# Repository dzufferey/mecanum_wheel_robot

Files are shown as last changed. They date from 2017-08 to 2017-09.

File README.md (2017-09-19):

# Mecanum wheels robot

A small omnidirectional wheeled robot.

The robot is designed as part of a series of tutorials covering: CAD, prototyping, and programming.

The project is split among the following directories:
- [body](body)
- [code](code)
- [pcb](pcb)

Not everything is in this repository.
You will also need:
- a model for the [mecanum wheels](https://github.com/dzufferey/scadla/blob/master/src/main/scala/scadla/examples/MecanumWheel.scala), or [alternatives](https://www.thingiverse.com/search?q=mecanum) like [this](https://www.thingiverse.com/thing:1203230)
- a case for Raspberry Pi (look on [Thingiverse](http://www.thingiverse.com/))

The [HOWTO.md](HOWTO.md) file describe how to put things together.

## Attributions

- [Bosch Blue 10.8 volt battery container](https://www.thingiverse.com/thing:1246842) by topias5 is licensed under the CC-BY-NC license.
- references and model for [A4988 Stepper Motor Driver Carrier, Black Edition](https://www.pololu.com/product/2128), license unclear ...
- [KiCAD module for the stepper dirvers](https://github.com/jharvey/Cinch_enclosure_template/tree/master/KICAD_Project/PCB-modules/pololu) by Jared Harvey, license unclear ...
- [rpi3-bottom_netfabb.stl](https://www.thingiverse.com/thing:2413372) by sachingm is licensed under CC-BY.

## License

The content of this project itself is licensed under the [Creative Commons Attribution 3.0 license](http://creativecommons.org/licenses/by/3.0/us/deed.en_US), and the source code in the `code` folder is licensed under the [MIT license](http://opensource.org/licenses/mit-license.php).

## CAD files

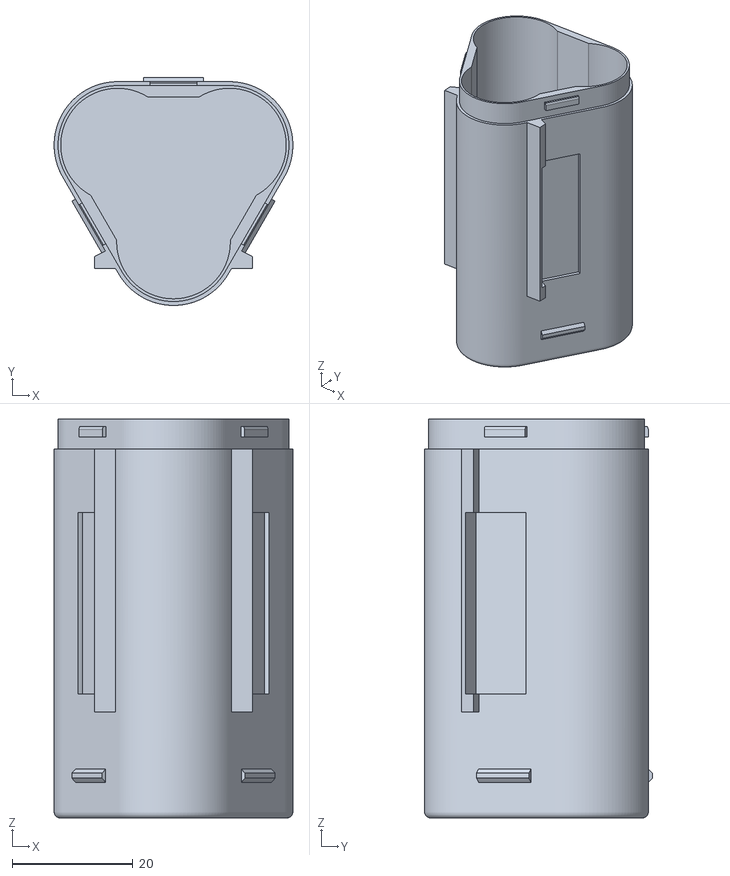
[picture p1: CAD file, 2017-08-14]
body/battery/Bosch_battery_108_body.stl
39.5 x 37.7 x 66.0

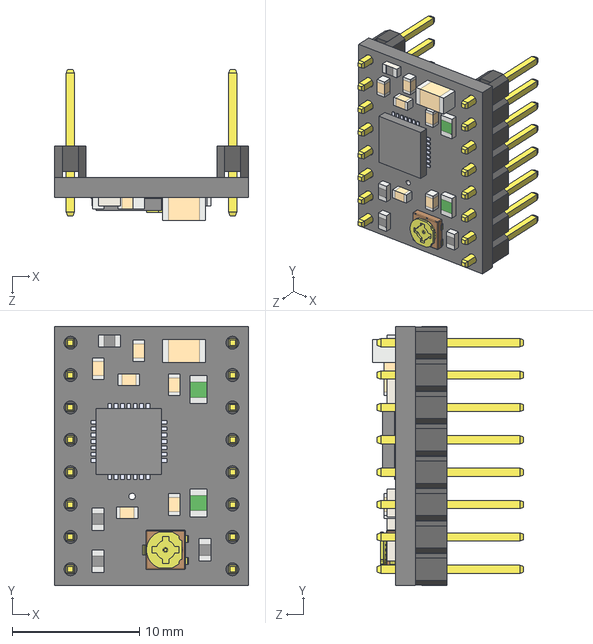
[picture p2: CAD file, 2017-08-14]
pcb/4_stepper_drivers/resources/a4988-stepper-motor-driver-carrier-black-edition.step
15.2 x 20.3 x 11.9 mm

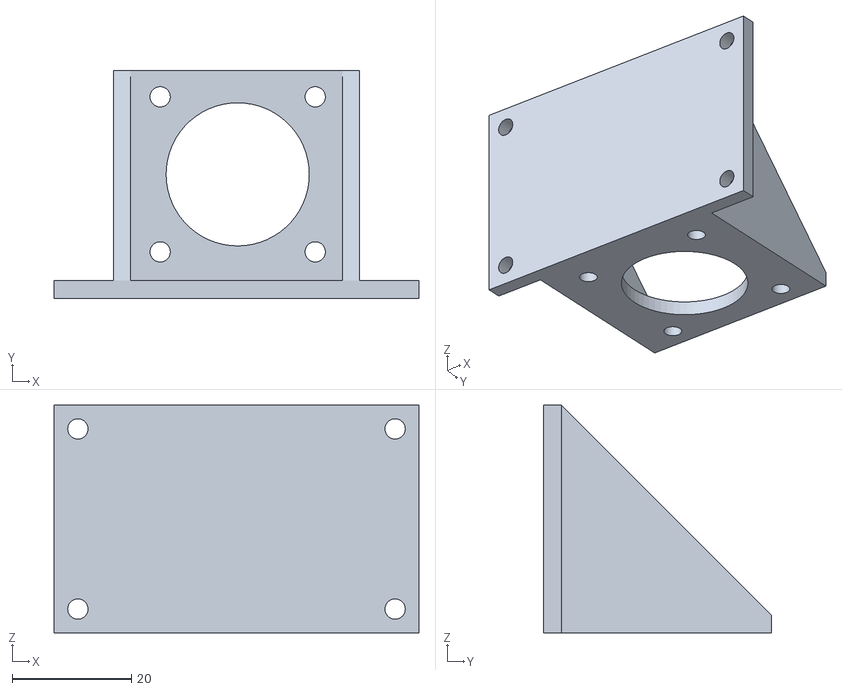
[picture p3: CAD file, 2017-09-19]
ready_to_make/body/nema14_bracket.stl
61.2 x 38.2 x 38.2

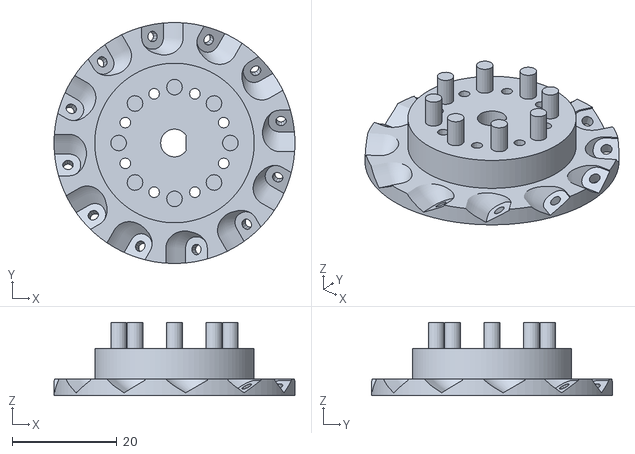
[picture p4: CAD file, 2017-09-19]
ready_to_make/body/wheel/lower1.stl
46.1 x 46.1 x 14.0

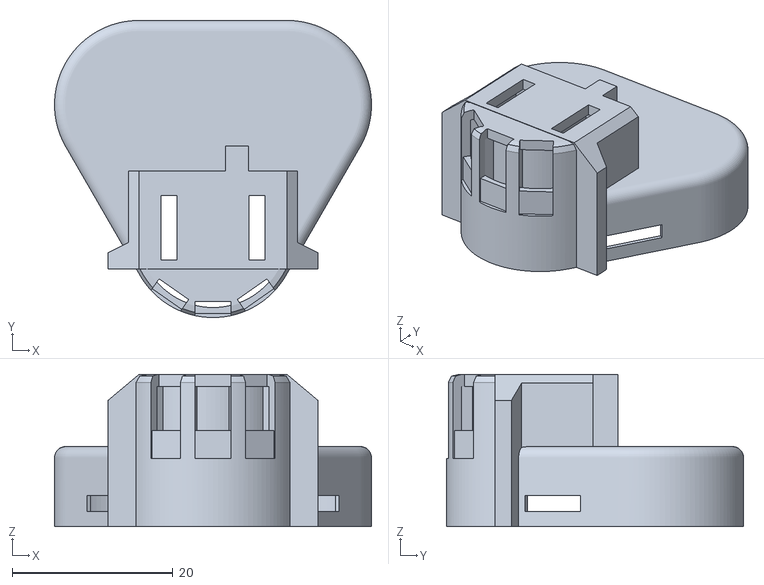
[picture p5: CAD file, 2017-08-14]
body/battery/Bosch_battery_108_top.stl
39.5 x 37.0 x 19.0

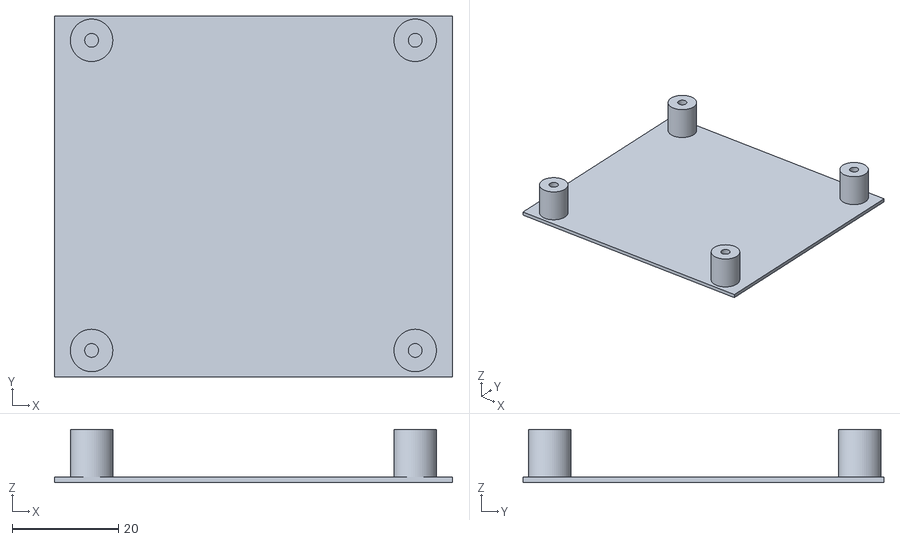
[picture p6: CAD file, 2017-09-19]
ready_to_make/body/pcb_base.stl
75.0 x 68.0 x 10.0

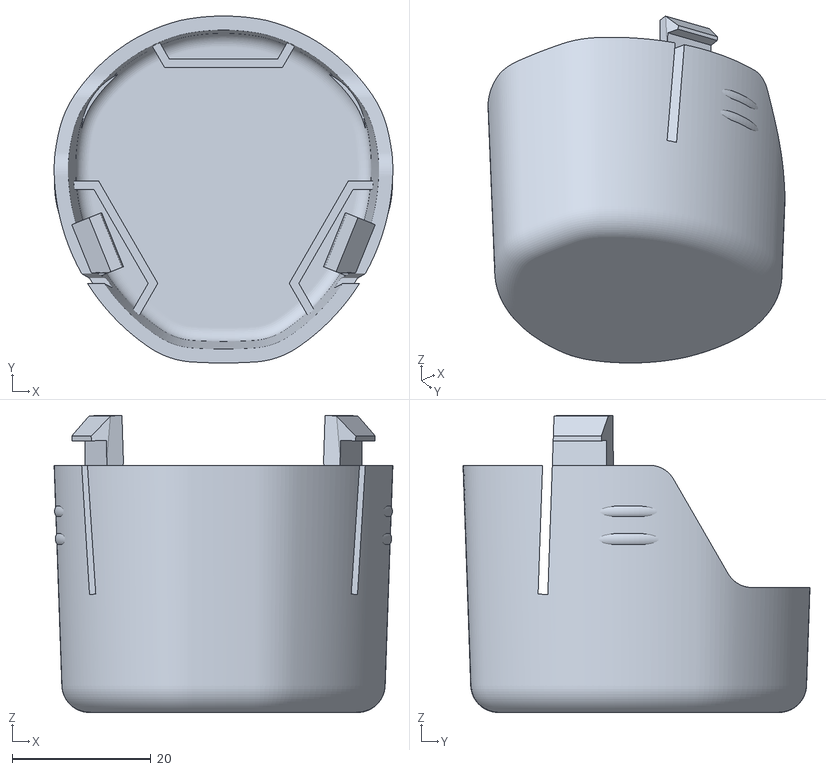
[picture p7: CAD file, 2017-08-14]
body/battery/Bosch_battery_108_cap.stl
48.8 x 50.0 x 42.8

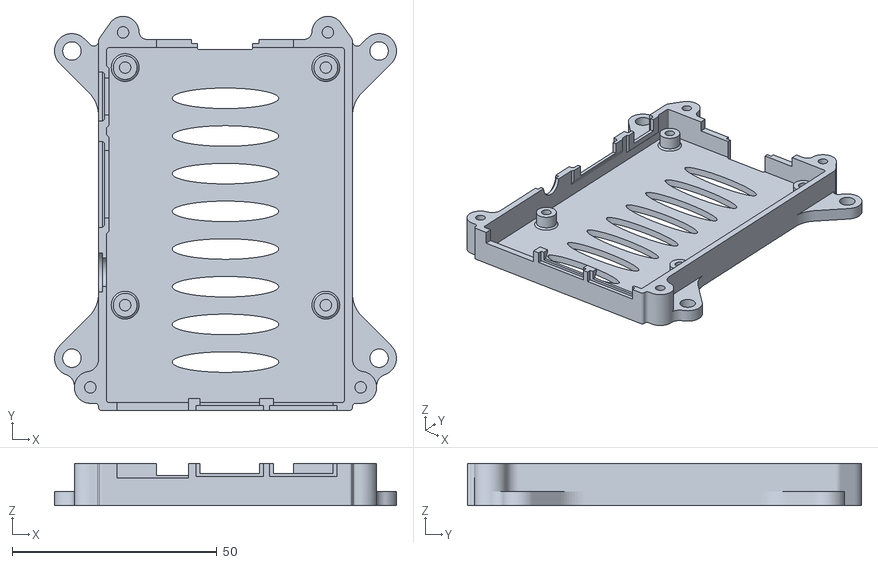
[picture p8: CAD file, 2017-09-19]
ready_to_make/body/rpi3-bottom_netfabb.stl
83.5 x 96.2 x 10.3

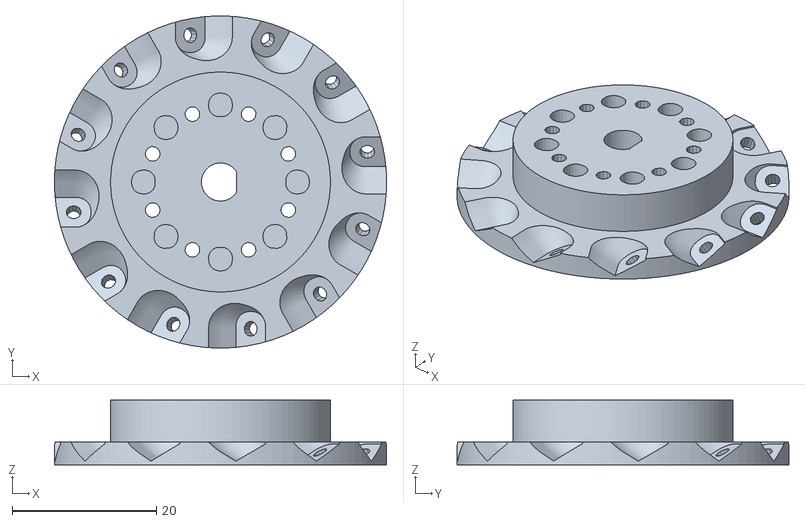
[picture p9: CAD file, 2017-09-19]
ready_to_make/body/wheel/upper1.stl
46.1 x 46.1 x 9.00

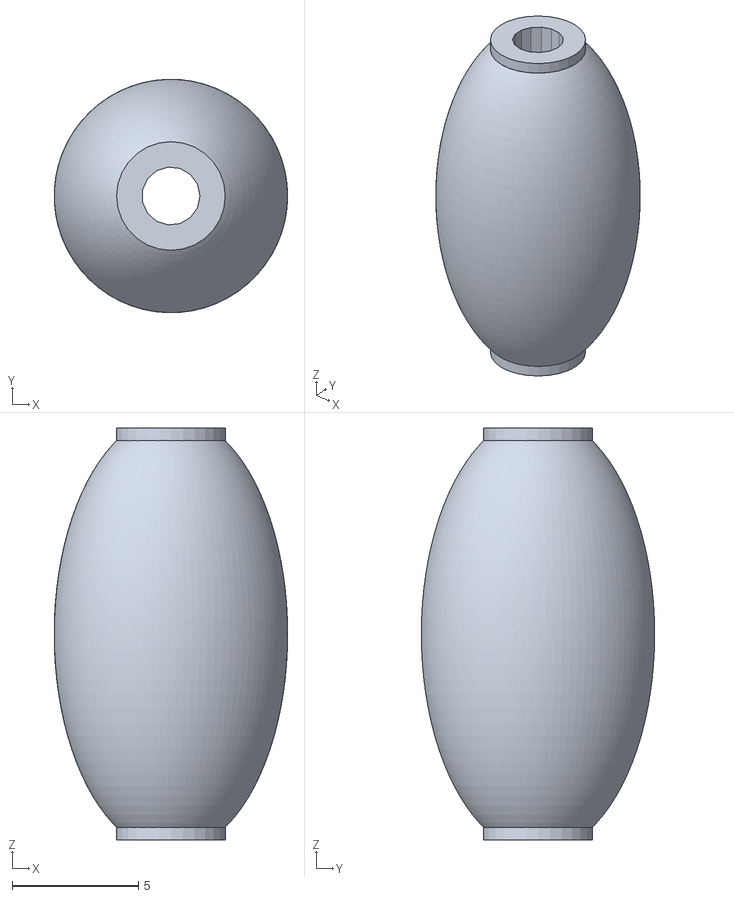
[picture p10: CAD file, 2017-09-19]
ready_to_make/body/wheel/roller.stl
9.23 x 9.24 x 16.3

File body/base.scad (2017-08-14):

$fn=60;

module pin(h = 10) {
    difference() {
        cylinder(r = 4, h = h);
        cylinder(r = 1.3, h = h);
    }
}

module base() {
    dx = 60.96;
    dy = 58.42;
    cube([75, 68, 1]);
    for (x = [0, dx])
        for (y = [0, dy])
            translate([7+x, 5 + y, 0]) pin();
}

base();

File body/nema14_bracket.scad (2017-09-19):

$fn=60;
wall=3;


tolerance = 0.2;
width = 35.2;
screw = 26;

r = (width - screw) / 2 + tolerance;
m3 = 1.5 + tolerance;

module shell() {
    difference() {
        hull(){
            difference() {
                translate([-wall,-wall,-wall]) cube([width+2*wall,width+wall,width+wall]);
                translate([-wall,0,0]) cube(width+2*wall);
            }
        }
        translate([-tolerance,-tolerance,-tolerance]) cube(width + 2*tolerance);
    }
    difference() {
        translate([-wall-10,-wall,-wall]) cube([width+2*wall+20,wall,width+wall]);
        for (x = [-6-wall, width + wall + 6]) {
            for (z = [4-wall,width-4]) {
                translate ([x,-wall, z]) rotate([-90,0,0]) translate ([0,0,-0.5]) cylinder(r=m3,h=wall+1);
             }
        }
    }
}

module complete() {
    difference() {
        translate([-r,-r, 0]) shell();
        translate([0,0,-wall]) {
            for (x = [0,screw]) {
                for (y = [0,screw]) {
                    translate ([x,y,0]) cylinder (r=m3,h=wall);
                }
            }
            translate ([screw/2,screw/2,0]) cylinder (r=12,h=wall);
        }
    }
}

complete();

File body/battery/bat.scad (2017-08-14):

$fn=60;

module top() {
    import("Bosch_battery_108_top.stl");
}

module mid() {
    import("Bosch_battery_108_body.stl");
}

module bot() {
    import("Bosch_battery_108_cap.stl");
}

module core(h) {
    rotate([0,0,30])cylinder(r=32, h=h,$fn=3);
}


module top_a() {
    intersection() {
        top();
        cylinder(r=25,h=10.0625);
    }
}

module top_b() {
    intersection() {
        top();
        translate([0,0,10.0625]) cylinder(r=25,h=15);
    }
}

module top2() {
    hull() intersection() {
        top_a();
        core(11);
    }
    top_a();
    hull() intersection() {
        top_b();
        core(30);
        translate([-10.5,-22.9,10]) cube([21,20,15]);
    }
    top_b();
}

module mid2(){
    hull() intersection() {
        mid();
        core(100);
    }
    mid();
}

module bot2(){
    hull() intersection() {
        bot();
        cylinder(r=30,h=18.0625);
    }
    hull() intersection() {
        bot();
        translate([0,0,18.0625]) cylinder(r=30,h=17.5);
    }
    hull() difference() {
        bot();
        translate([0,0,0]) cylinder(r=30,h=17.6 + 18.0625);
        translate([0,0,17.5 + 21.5]) cylinder(r=30,h=10);
    }
    hull() difference() {
        bot();
        translate([0,0,0]) cylinder(r=30,h=17.5 + 21.5);
    }
}

module bat() {
    translate([0,0,3]) {
        translate([0,0,61]) top2();
        mid2();
    }
    bot2();
}

module bigger_bat() {
    minkowski(){
        bat();
        sphere(r=0.5, $fn=30);
    }
}

module holder() {
    difference() {
        translate([0,2,0]) cylinder(r=25, h=47.5);
        translate([0,0,83]) rotate([180,0,0]) bigger_bat();
    }
}

module contacts() {
    translate([4.5,6,0]) cube([2,8,10]);
    translate([-6.5,6,0]) cube([2,8,10]);
}

holder();

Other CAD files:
ready_to_make/body/wheel/lower2.stl
ready_to_make/body/wheel/upper2.stl

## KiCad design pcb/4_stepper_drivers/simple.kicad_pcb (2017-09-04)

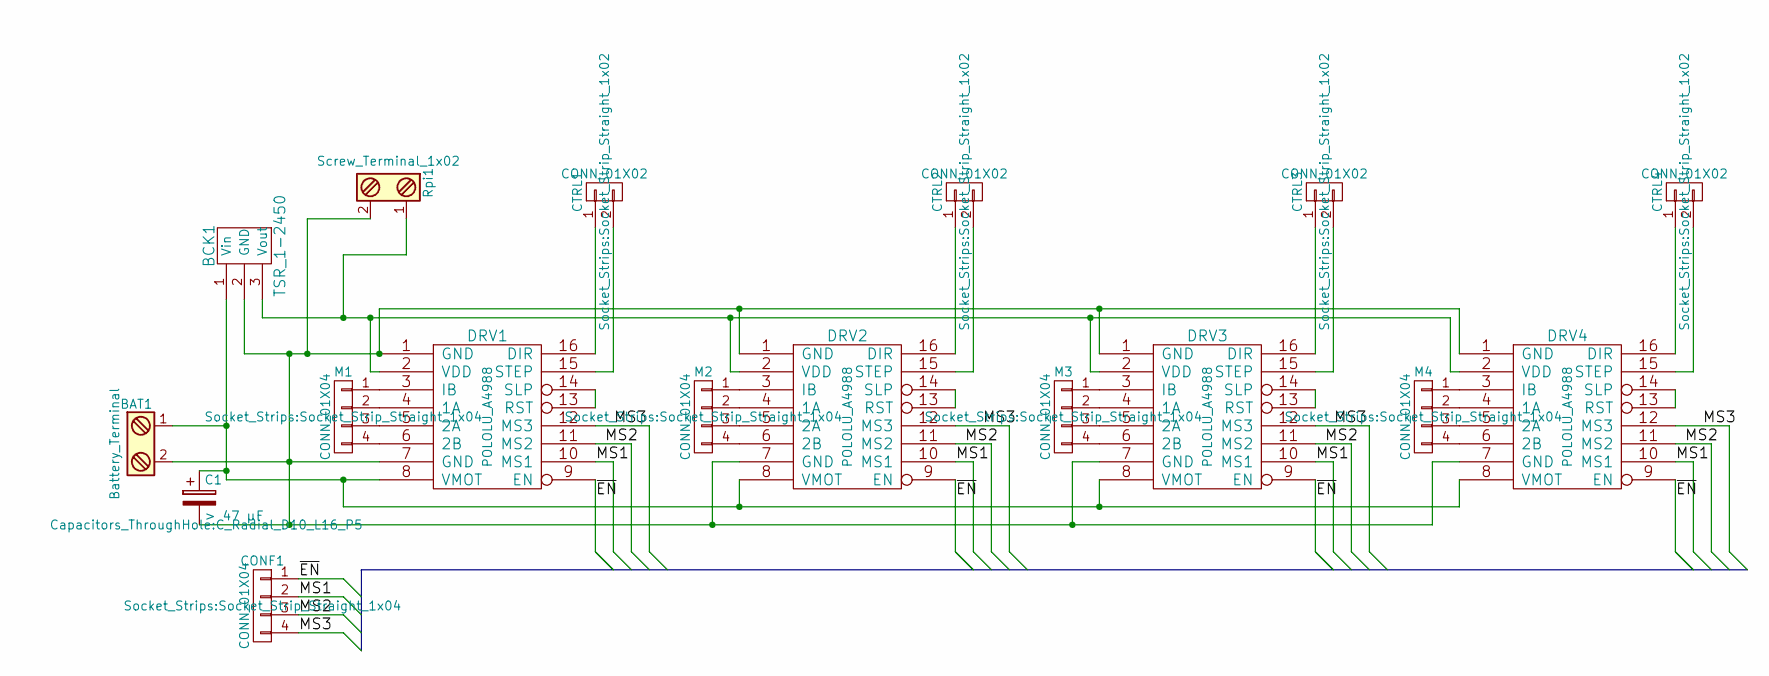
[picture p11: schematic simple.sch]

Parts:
BAT1: Battery_Terminal; TerminalBlock_Pheonix_MKDS1.5-2pol
BCK1: TSR_1-2450; TO-220_Neutral123_PadsOnly
C1: > 47 µF; C_Radial_D10_L16_P5
CONF1: CONN_01X04; Socket_Strip_Straight_1x04
CTRL1, CTRL2, CTRL3, CTRL4: CONN_01X02; Socket_Strip_Straight_1x02
DRV1, DRV2, DRV3, DRV4: POLOLU_A4988; Pololu_a4988
M1, M2, M3, M4: CONN_01X04; Socket_Strip_Straight_1x04
Rpi1: Screw_Terminal_1x02; TerminalBlock_Pheonix_MPT-2.54mm_2pol

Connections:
/MS1: CONF1.2, DRV1.10 (MS1), DRV2.10 (MS1), DRV3.10 (MS1), DRV4.10 (MS1)
/MS2: CONF1.3, DRV1.11 (MS2), DRV2.11 (MS2), DRV3.11 (MS2), DRV4.11 (MS2)
/MS3: CONF1.4, DRV1.12 (MS3), DRV2.12 (MS3), DRV3.12 (MS3), DRV4.12 (MS3)
/~EN: CONF1.1, DRV1.9 (EN), DRV2.9 (EN), DRV3.9 (EN), DRV4.9 (EN)
unnamed: BAT1.1 (+), BCK1.1 (Vin), C1.1, DRV1.8 (VMOT), DRV2.8 (VMOT), DRV3.8 (VMOT), DRV4.8 (VMOT)
unnamed: BAT1.2 (-), BCK1.2 (GND), C1.2, DRV1.1 (GND), DRV1.7 (GND), DRV2.1 (GND), DRV2.7 (GND), DRV3.1 (GND), DRV3.7 (GND), DRV4.1 (GND), DRV4.7 (GND), Rpi1.2
unnamed: BCK1.3 (Vout), DRV1.2 (VDD), DRV2.2 (VDD), DRV3.2 (VDD), DRV4.2 (VDD), Rpi1.1
unnamed: CTRL1.1, DRV1.16 (DIR)
unnamed: CTRL1.2, DRV1.15 (STEP)
unnamed: CTRL2.1, DRV2.16 (DIR)
unnamed: CTRL2.2, DRV2.15 (STEP)
unnamed: CTRL3.1, DRV3.16 (DIR)
unnamed: CTRL3.2, DRV3.15 (STEP)
unnamed: CTRL4.1, DRV4.16 (DIR)
unnamed: CTRL4.2, DRV4.15 (STEP)
unnamed: DRV1.3 (IB), M1.1
unnamed: DRV1.4 (1A), M1.2
unnamed: DRV1.5 (2A), M1.3
unnamed: DRV1.6 (2B), M1.4
unnamed: DRV1.13 (RST), DRV1.14 (SLP)
unnamed: DRV2.3 (IB), M2.1
unnamed: DRV2.4 (1A), M2.2
unnamed: DRV2.5 (2A), M2.3
unnamed: DRV2.6 (2B), M2.4
unnamed: DRV2.13 (RST), DRV2.14 (SLP)
unnamed: DRV3.3 (IB), M3.1
unnamed: DRV3.4 (1A), M3.2
unnamed: DRV3.5 (2A), M3.3
unnamed: DRV3.6 (2B), M3.4
unnamed: DRV3.13 (RST), DRV3.14 (SLP)
unnamed: DRV4.3 (IB), M4.1
unnamed: DRV4.4 (1A), M4.2
unnamed: DRV4.5 (2A), M4.3
unnamed: DRV4.6 (2B), M4.4
unnamed: DRV4.13 (RST), DRV4.14 (SLP)

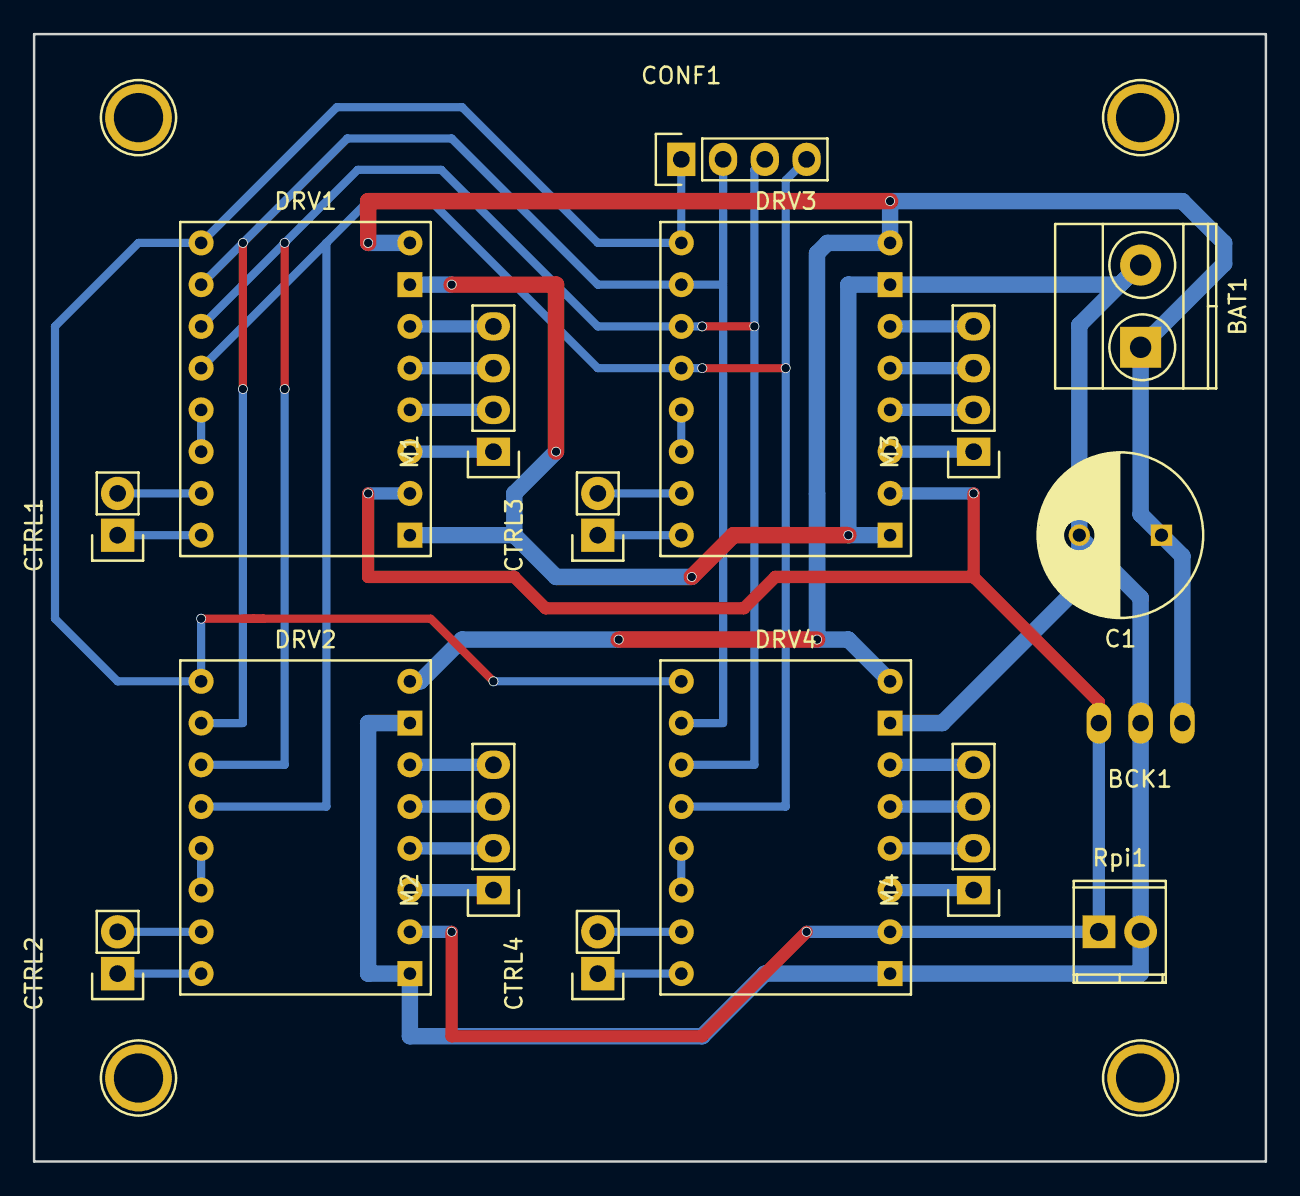
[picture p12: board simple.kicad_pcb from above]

Board: 2 copper layers, 74.9 x 68.6 mm, 17 parts (0 on the bottom side), 35 nets.

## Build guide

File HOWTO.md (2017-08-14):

# How To

## Notes

This projects use stepper motors because I had a bunch of them lying around.
However, DC motors with H-bridge for drivers would be more appropriate.

## BOM

* Raspberry Pi Model 3
* 4x NEMA 14 stepper motors
* 4x A4988 Stepper Motor Driver Carrier by Pololu
* DC-DC buck converter (TSR 1-2450 by Traco Electronic AG)
* Capacitor: 330 uF, 35V, electrolytic, radial
* on/off switch (any kind > 2A will do)
* screw terminal
* micro USB cable
* a bunch of (fe)male headers, wires, screws, ...
* board (to hold things together, any kind of scrap wood will do)

## Prerequisites

### Tools

* 3D printer
* CNC mill with 0.8, 1, and 3mm bits
* soldering iron
* screwdrivers
* drill
* hot glue gun
* precision knife
* tweezers
* ...

### Software

* [KiCad](http://kicad-pcb.org/)
* [OpenSCAD](http://www.openscad.org/)
* nmap, ssh cilent (to find and connect to the Raspberry Pi)
* Slicer for your 3D printer, e.g., [Slic3r](http://slic3r.org/)
* [FlatCAM](http://flatcam.org/)

## Raspberry Pi setup

* Headless setup for the Raspberry Pi 3:
  - http://blog.self.li/post/63281257339/raspberry-pi-part-1-basic-setup-without-cables for the basic setup, finding the rpi over the network, and sshing into it.
  - On recent images, you need to enable SSH: https://caffinc.github.io/2016/12/raspberry-pi-3-headless/
* To find your rpi I recommend using `sudo nmap -sP -n XXX.YYY.ZZZ.0/24` where XXX, YYY, ZZZ is the ip of subnetwork. This should also show the MAC address (useful if there are multiple rpi on your network).
* Install [Wiring Pi](http://wiringpi.com/download-and-install/)

## Building the robot

ToDo ...

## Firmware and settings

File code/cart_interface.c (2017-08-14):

#include "gui.h"
#include "motors.h"

int main(int argc, char *argv[]) {
    
    int side = 0;
    int straight = 0;
    int rotate = 0;

    motors_setup();
    motors_start(straight, side, rotate);

    WINDOW *my_win = window_setup();
    show_values(my_win, straight, side, rotate);

    bool again = true;
    while(again) {
        int result = gui_loop(my_win, &straight, &side, &rotate);
        switch (result) {
            case LOOP_TERMINATE:
                again = false;
                break;
            case LOOP_NOTHING:
                break;
            case LOOP_CHANGED:
                motors_update(straight, side, rotate);
                break;
        }
    }

    motors_shutdown();
    window_shutdown();

    exit(0);
}

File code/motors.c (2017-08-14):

#include "motors.h"

#include <pthread.h>
#include <stdlib.h>
#include <ctype.h>
#include <stdbool.h>
#include <math.h>
#include <stdio.h>

#include <wiringPi.h>

// for looping

/*
motor ID:
0: front left
1: back left
2: front right
3: back right
*/

const int motors_pin_dir[4] = {
    MOTOR_1_DIR,
    MOTOR_2_DIR,
    MOTOR_3_DIR,
    MOTOR_4_DIR 
};

const int motors_pin_stp[4] = {
    MOTOR_1_STP,
    MOTOR_2_STP,
    MOTOR_3_STP,
    MOTOR_4_STP
};

// for inter thread communication

pthread_t motor_thread;

typedef struct {
    bool directions[4]; // 0/false means LOW
    int dt[4];
} motors_pulses;

motors_pulses* volatile pulses;



void motors_setup() {
    wiringPiSetup();

    pinMode(MOTOR_1_DIR, OUTPUT);
    pinMode(MOTOR_1_STP, OUTPUT);
    pinMode(MOTOR_2_DIR, OUTPUT);
    pinMode(MOTOR_2_STP, OUTPUT);
    pinMode(MOTOR_3_DIR, OUTPUT);
    pinMode(MOTOR_3_STP, OUTPUT);
    pinMode(MOTOR_4_DIR, OUTPUT);
    pinMode(MOTOR_4_STP, OUTPUT);

    pinMode(NEN, OUTPUT);
    pinMode(MS1, OUTPUT);
    pinMode(MS2, OUTPUT);
    pinMode(MS3, OUTPUT);

    digitalWrite(NEN, HIGH);
    motors_stepping(MICROSTEP);
}

/*  A4988 config pins
 *  MS1     MS2     MS3     Microstep Resolution
 *  Low     Low     Low     Full step
 *  High    Low     Low     Half step
 *  Low     High    Low     Quarter step
 *  High    High    Low     Eighth step
 *  High    High    High    Sixteenth step
 */
void motors_stepping(int microsteps) {
    switch (microsteps) {
        case 1:
            digitalWrite(MS1, LOW);
            digitalWrite(MS2, LOW);
            digitalWrite(MS3, LOW);
            break;
        case 2:
            digitalWrite(MS1, HIGH);
            digitalWrite(MS2, LOW);
            digitalWrite(MS3, LOW);
            break;
        case 4:
            digitalWrite(MS1, LOW);
            digitalWrite(MS2, HIGH);
            digitalWrite(MS3, LOW);
            break;
        case 8:
            digitalWrite(MS1, HIGH);
            digitalWrite(MS2, HIGH);
            digitalWrite(MS3, LOW);
            break;
        case 16:
            digitalWrite(MS1, HIGH);
            digitalWrite(MS2, HIGH);
            digitalWrite(MS3, HIGH);
            break;
    }
}

void* motors_loop(void* ptr) {
    //local variable to keep track of the pulses
    motors_pulses* old_pulses = NULL;
    bool directions[4] = {false, false, false, false};
    int delta[4] = {0, 0, 0, 0};
    
    //default direction
    digitalWrite(MOTOR_1_DIR, LOW);
    digitalWrite(MOTOR_2_DIR, LOW);
    digitalWrite(MOTOR_3_DIR, LOW);
    digitalWrite(MOTOR_4_DIR, LOW);

    //enable the steppers
    digitalWrite(NEN, LOW);

    unsigned int time = micros();
    while(pulses != NULL) {

        //pulses changed, need to check the directions
        if (pulses != old_pulses) {
            free(old_pulses);
            old_pulses = pulses;
            for (int i = 0; i < 4; ++i) {
                if (old_pulses->directions[i] != directions[i]) {
                    directions[i] = old_pulses->directions[i];
                    digitalWrite(motors_pin_dir[i], directions[i] ? HIGH : LOW);
                    delta[i] = 2 * old_pulses->dt[i] - LOOP_USEC; //can we do better ?
                }
            }
            //XXX
            time = micros();
        }

        //set HIGH the pins that needs to be pulsed
        for (int i = 0; i < 4; ++i) {
            if(delta[i] > 0) {
                digitalWrite(motors_pin_stp[i], HIGH);
                delta[i] -= 2*LOOP_USEC;
            }
        }

        //to make sure the drivers record the pulse
        //delayMicroseconds(1);
        for (int i = 0; i < 4; ++i) {
            delta[i] += 2 * old_pulses->dt[i];
        }

        // back to LOW state
        for (int i = 0; i < 4; ++i) {
            digitalWrite(motors_pin_stp[i], LOW);
        }

        // wait for the next iteration 
        unsigned int expected = time + LOOP_USEC;
        unsigned int new_time = micros();
        unsigned int how_long = expected - new_time;
        if (how_long > LOOP_USEC) {
            //fprintf(stderr, "time: %i, new_time: %i, how_long: %i\n", time, new_time, how_long);
            //exit(-3);
        } else {
            //delayMicroseconds(how_long);
            while (micros() < expected) {}
        }
        time = new_time;
    }

    //disable the steppers
    digitalWrite(NEN, HIGH);
    return NULL;
}

void motors_shutdown() {
    pulses = NULL;
    __sync_synchronize();
    pthread_join( motor_thread, NULL);
}

void compute_pulses(motors_pulses* pulses, int straight, int side, int rotate) {
    // the overal motion for each motor
    int motors[4] = { 0, 0, 0, 0};
    motors[0] = COEFF_STRAIGHT * straight + COEFF_SIDE * side - COEFF_ROTATE * rotate;
    motors[1] = COEFF_STRAIGHT * straight - COEFF_SIDE * side - COEFF_ROTATE * rotate;
    motors[2] = COEFF_STRAIGHT * straight - COEFF_SIDE * side + COEFF_ROTATE * rotate;
    motors[3] = COEFF_STRAIGHT * straight + COEFF_SIDE * side + COEFF_ROTATE * rotate;
    for (int i = 0; i < 4; ++i) {
        pulses->directions[i] = motors[i] <= 0;
        pulses->dt[i] = abs(motors[i]) * LOOP_USEC / MAX_VALUE;
    }
}

void motors_start(int straight, int side, int rotate) {
    if (pulses == NULL) {
        pulses = (motors_pulses*) malloc(sizeof(motors_pulses));
        compute_pulses(pulses, straight, side, rotate);
        __sync_synchronize();
        int err = pthread_create( &motor_thread, NULL, motors_loop, (void*) NULL);
        if(err) {
            exit(-1);
        }
    }
}

void motors_update(int straight, int side, int rotate) {
    motors_pulses* mp = (motors_pulses*) malloc(sizeof(motors_pulses));
    compute_pulses(mp, straight, side, rotate);
    __sync_synchronize();
    pulses = mp;
    __sync_synchronize();
}

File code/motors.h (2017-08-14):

#pragma once

#define MOTOR_1_DIR  0
#define MOTOR_1_STP  1
#define MOTOR_2_DIR  2
#define MOTOR_2_STP  3
#define MOTOR_3_DIR  4
#define MOTOR_3_STP  5
#define MOTOR_4_DIR  6
#define MOTOR_4_STP  7
#define NEN  8
#define MS1  9
#define MS2  10
#define MS3  11

#define MAX_VALUE 40
#define COEFF_STRAIGHT 1
#define COEFF_SIDE 2
#define COEFF_ROTATE 1

#define MICROSTEP 16
#define LOOP_USEC 250

/*
The thread that deals with making pulse to the stepper is base on https://en.wikipedia.org/wiki/Bresenham%27s_line_algorithm.

Sychronization between the thread. In c99 and gcc we can use:
- __thread for threadlocal variables
- __sync_synchronize() for memory barrier
        
motion  | front left | front right | back left | back right |
--------|------------|-------------|-----------|------------|
straight|       1    |          1  |        1  |        1   |
side    |       2    |         -2  |       -2  |        2   |
rotate  |      -1    |          1  |       -1  |        1   |
--------|------------|-------------|-----------|------------|
the factor 2 for the side comes from the 30° angle of the rollers

*/

void motors_setup();
void motors_shutdown();
void motors_start(int straight, int side, int rotate);
void motors_update(int straight, int side, int rotate);
void motors_stepping(int microsteps);

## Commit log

2017-08-14 adding the source files
    [Bosch_battery_108_body.stl, Bosch_battery_108_cap.stl, Bosch_battery_108_top.stl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]
2017-09-04 absolute -> relative paths
    [simple.kicad_pcb]
2017-09-04 footprint lib as project specific lib
2017-09-19 adding some more files
    [lower1.stl, lower2.stl, nema14_bracket.scad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]
